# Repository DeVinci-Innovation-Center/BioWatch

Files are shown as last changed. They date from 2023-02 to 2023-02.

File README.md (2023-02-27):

# BioWatch
The BioWatch is a smartwatch prototyping for developing wearable biosensors and real-time data visualization. This electronic project aims at **facilitating the integration (or wireless connection) in a smartwatch of innovative wearable sensors**. The BioWatch allows rapid implementation of minimally invasive electrochemical biosensors. 

<p align="center">
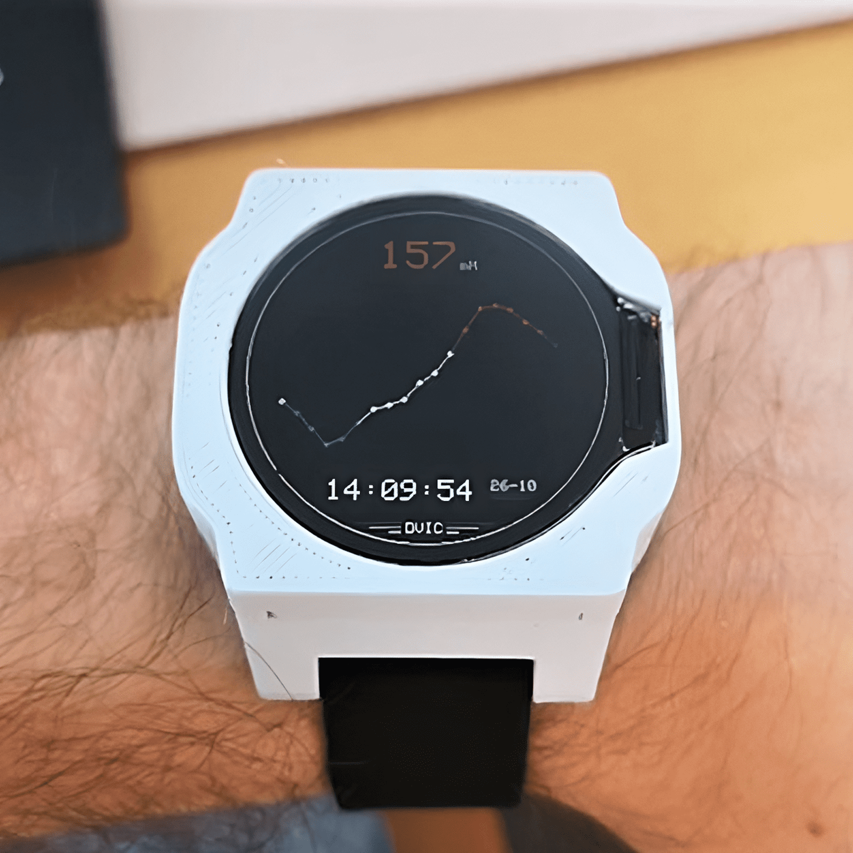
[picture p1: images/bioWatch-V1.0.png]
  
</p>

# System overview

<p align="center">
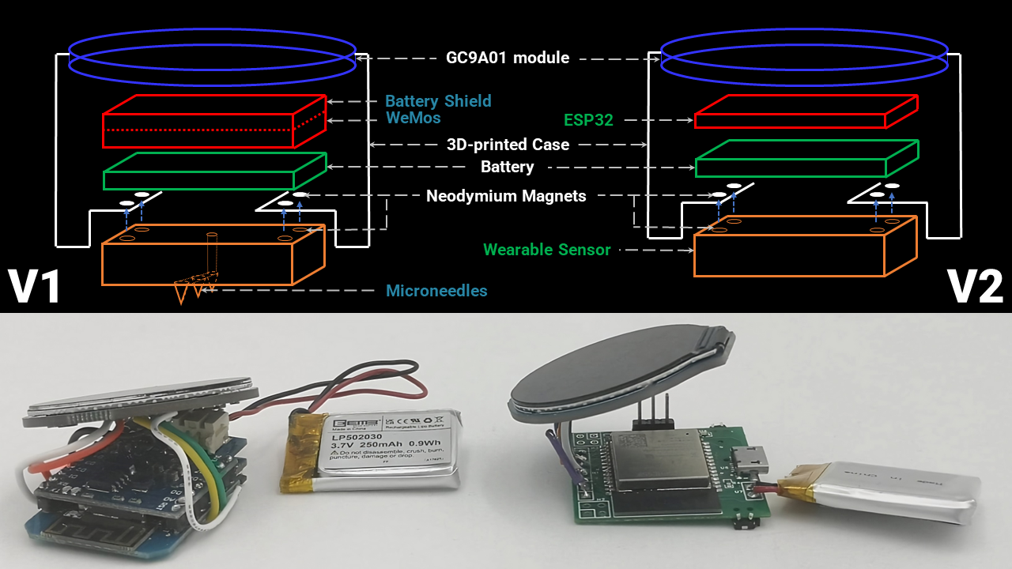
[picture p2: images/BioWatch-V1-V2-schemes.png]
  
</p>

# Requierments

To build the BioWatch you need the following components:
* A [CG9A01 round LCD screen](https://www.kubii.fr/ecrans-supports/3242-ecran-rond-lcd-1-28-pouces-3272496305625.html),
* An [ESP8266 WeMos D1 mini](https://www.amazon.fr/ESP8266-ESP-12F-D%C3%A9veloppement-NodeMCU-Compatible/dp/B093G72SHN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),
* A [battery shield](https://www.amazon.fr/AZDelivery-Batterie-lithium-Arduino-incluant/dp/B07XG817P8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) for WeMos D1 mini,
* A 3.7V 250mAh battery ref [LP502030](https://www.amazon.fr/EEMB-Batterie-Rechargeable-Navigation-Enregistreur/dp/B08FD3V6TF).
  
# Quickstart

**1. Download and 3D-print the [watch case](https://github.com/DeVinci-Innovation-Center/BioWatch/tree/main/hardware) of your choice.** 

*Version 1.0 includes the battery in the case, while V1.1 provides for the battery to be integrated in the bracelet.*

**2. Assembled the shield with the WeMos. Weld the GC9A01 using wires with the following dimensions:**
<p align="center">
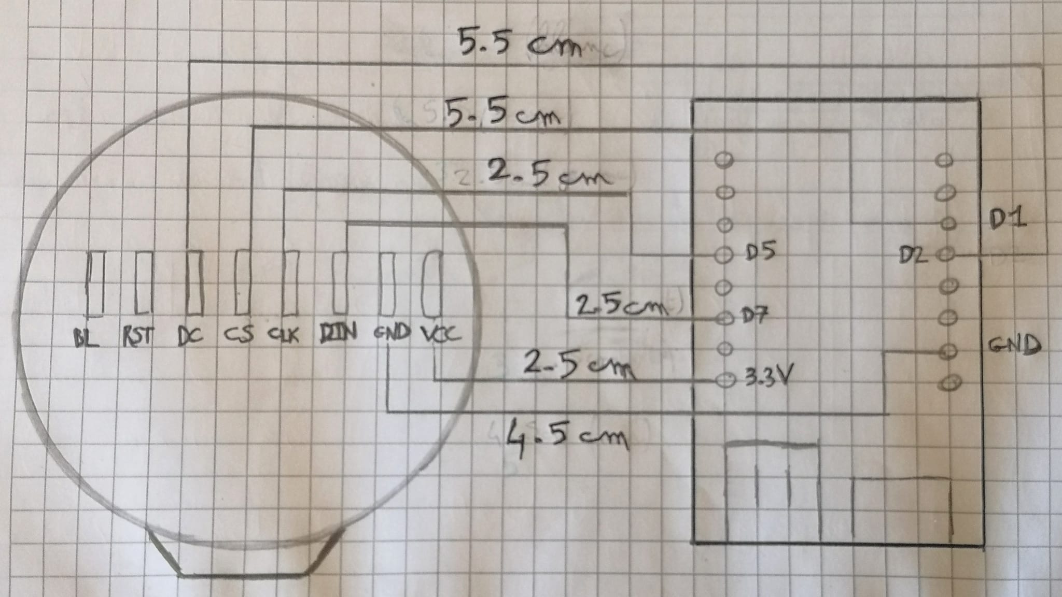
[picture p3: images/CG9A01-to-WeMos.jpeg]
  
</p>

**3. Upload a code in the [graphic_design folder](https://github.com/DeVinci-Innovation-Center/BioWatch/tree/main/ecflex-to-biowatch_wireless_communication/biowatch_client/graphic_design) to program the GC9A01 driver. [print_graph-and_time](https://github.com/DeVinci-Innovation-Center/BioWatch/tree/main/ecflex-to-biowatch_wireless_communication/biowatch_client/graphic_design/print_graph_and_time) is the functional interface to print sensor data.**

**4. Insert the charged battery into the JST port of the shield and carefully insert the assembly into the case.**

**5. Close the case with the lid and add a standard watchband.**

# Biosensor-to-smartwatch wireless communication
This project includes a wireless communication solution between an ec-Flex from [Zimmer&Peacock](https://www.zimmerpeacocktech.com/products/) and a homemade smartwatch. Find the Quickstart to connect and configure an ecFlex to the BioWatch on the from [Biosensor-to-smartwatch_wireless_communication GitHub page](https://github.com/DeVinci-Innovation-Center/Biosensor-to-smartwatch_wireless_communication), and [a tutorial](https://dvic.devinci.fr/tutorial/glucose-biosensor) to buid a wearable glucose sensor connected to the BioWatch.

# Project advancement & Future works

- [x] Write an Arduino script using the GFX library that displays time, glucose concentration, and temperature (numerical values) on the GC9A01 screen.
- [x] Write an Arduino script using the GFX library that displays a curve representing the glucose concentration evolution on the GC9A01 screen.
- [x] Assemble the BioWatch V1.0.
- [x] Minimize the size of the BioWatch by assembling the BioWatch V1.1 with the battery in the bracelet. 
- [x] Connect the ec-Flex to the BioWatch.
- [x] Design the BioWatch interface. Print time, date, sensor value and history.
- [ ] Design the BioWatch V2 PCB.
- [ ] Integrate a modular pulse sensor to the BioWatch V2 and read the data in real-time.

***

<p align="center">
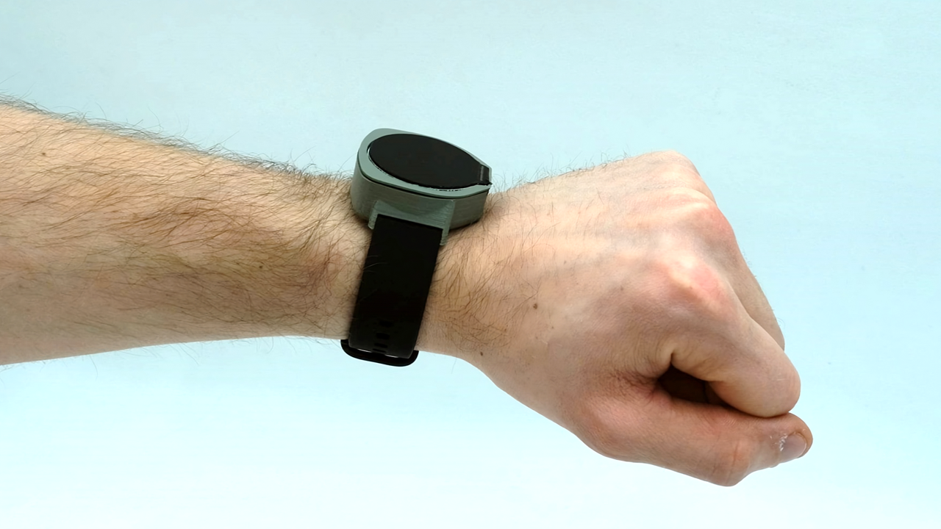
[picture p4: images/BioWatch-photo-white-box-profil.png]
  
</p>

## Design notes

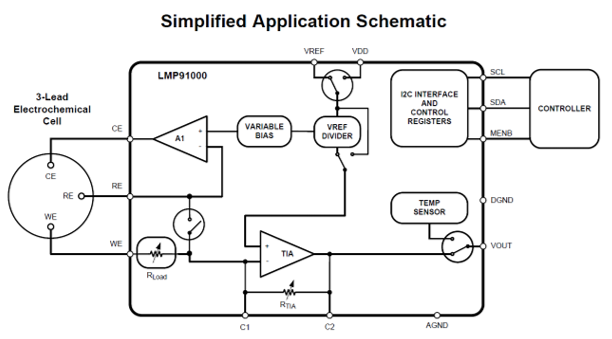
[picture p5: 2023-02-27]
images/LMP91000_AFE_simplified_schematic.png

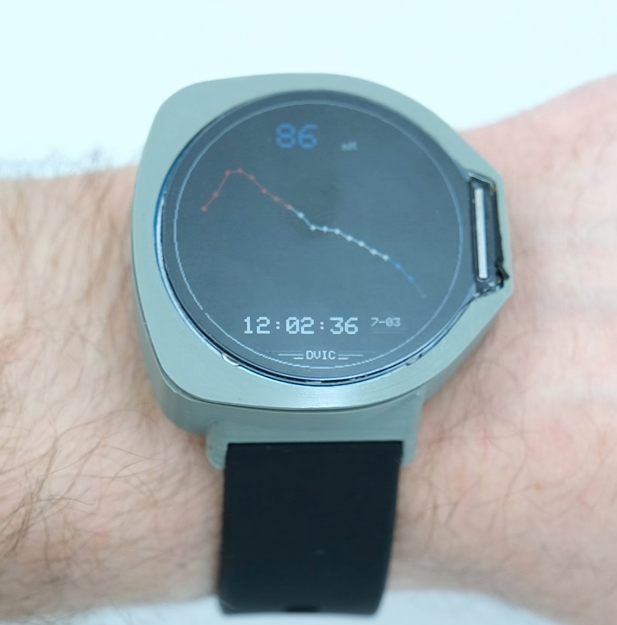
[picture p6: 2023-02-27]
hardware/case_modelizations_V1/bioWatch-V1.1.jpeg

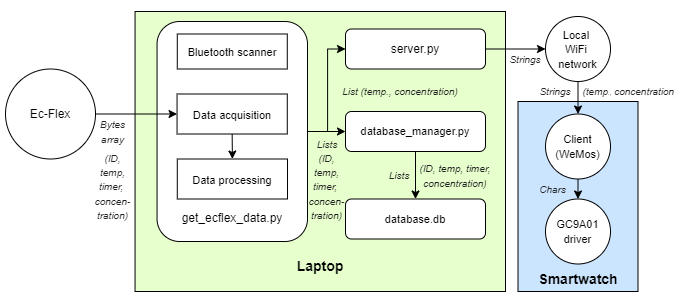
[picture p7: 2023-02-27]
images/deployment_diagramV2.png

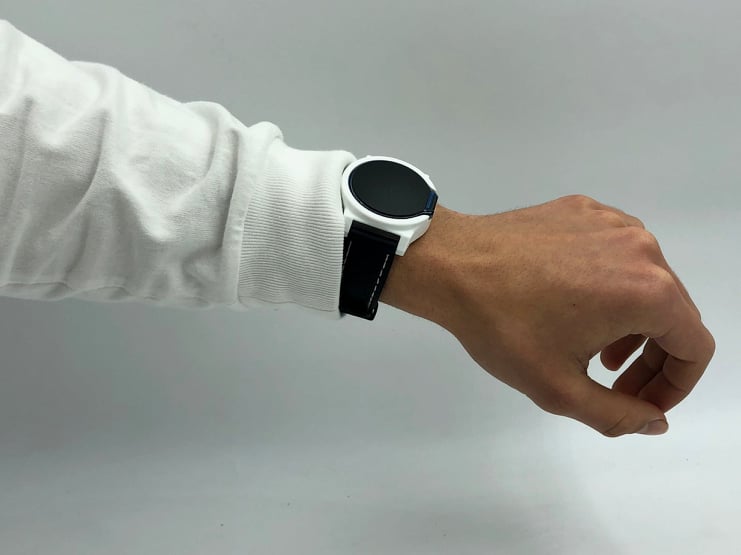
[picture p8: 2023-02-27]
images/SmartWatch_V0_white.jpg

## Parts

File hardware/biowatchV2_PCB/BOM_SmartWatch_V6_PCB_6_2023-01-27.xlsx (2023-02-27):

No. | Quantity | Comment | Designator | Footprint | Value | Manufacturer Part | Manufacturer | Supplier Part | Supplier
1 | 1 | CAPCER0.1UF16VX5R0603,CAPCER0.1UF25VX5R0603,CAPCER0.1UF16VX7R0603 | C1 | C0603 |  | CAPCER0.1UF16VX5R0603,CAPCER0.1UF25VX5R0603,CAPCER0.1UF16VX7R0603 | null | C9900012833 | LCSC
2 | 1 | 10uF | C2 | C0603 |  | 10uF | SAMSUNG(三星) | C15415 | LCSC
3 | 1 | PZ254V-11-07P | H1 | HDR-TH_7P-P2.54-V-M |  | PZ254V-11-07P | XFCN(兴飞) | C492406 | LCSC
4 | 2 | B-2100S04P-B110 | H2,H3 | HDR-TH_4P-P2.54-V-M-R2-C2-S2.54-1 |  | B-2100S04P-B110 | Ckmtw(灿科盟) | C124362 | LCSC
5 | 1 | H4: header 1x3 programmation serial | H4 | HEADER3L |  | Headers Pins2.54mm1*10P |  | C57369 | LCSC
6 | 1 | 1.2kΩ | R1 | R0603 |  | RMC06031.2K5%N | Tyohm(幸亚电阻) | C269681 | LCSC
7 | 2 | 1kΩ | R2,R3 | R0603 |  | 0603WAD1001T5E | UNI-ROYAL(厚声) | C51218 | LCSC
8 | 2 | 10kΩ | R4,R5 | R0603 |  | RNCS0603BKE10K0 | SEI(Stackpole Electronics Inc.) | C346660 | LCSC
9 | 1 | TA-3525-A3 | SW1 | SW-SMD_3P-L9.1-W3.5-P2.50-EH6.8 |  | TA-3525-A3 | Yuandi(元迪) | C514020 | LCSC
10 | 1 | ESP32-WROOM-32E-H4 | U0 | WIFI-SMD_ESP32-WROOM-32E |  | ESP32-WROOM-32E-H4 | ESPRESSIF(乐鑫) | C3013935 | LCSC
11 | 1 | TP4056 | U1 | ESOP-8_L4.9-W3.9-P1.27-LS6.0-BL-EP |  | TP4056 | TPOWER(天源) | C382139 | LCSC
12 | 1 | LED0603R | U2 | LED0603-R-RD |  | LED0603R | null | C9900017730 | LCSC
13 | 2 | LED0603B | U3,U4 | LED0603-RD |  | LED0603B | null | C9900005354 | LCSC
14 | 1 | BUTTON1 | U5 | SW-SMD_L7.8-W3.5-P4.00-EH |  | ButtonTACT_3x6x3.5 | null | C9900004514 | LCSC
15 | 1 | BUTTON2 | U6 | SW-SMD_L7.8-W3.5-P4.00-EH |  | ButtonTACT_3x6x3.5 | null | C9900004514 | LCSC
16 | 1 | DM254R-11-02-85 | U7 | HDR-TH_2P-P2.54-V-F |  | DM254R-11-02-85 | DEALON(德艺隆) | C2935973 | LCSC
17 | 1 | USB-MICRO-5P | U8 | MICRO-USB-SMD_MICRO-USB-A9 |  | USB-Micro-5P | null | C9900014288 | LCSC

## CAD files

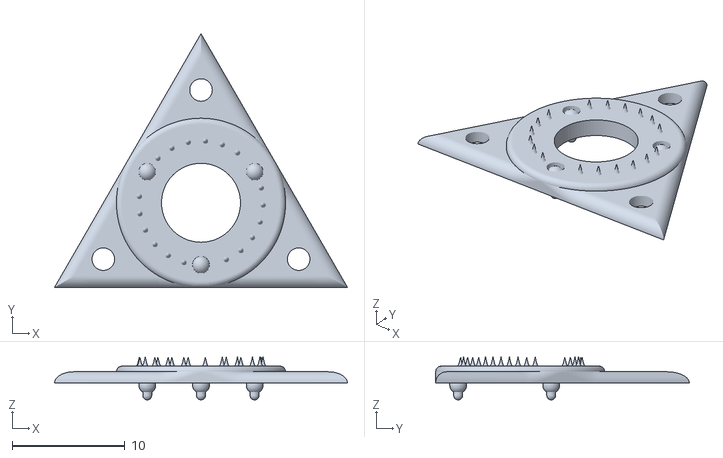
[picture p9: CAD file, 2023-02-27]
embedded_sensors/lmp91000/microneedles/Microneedles.stl
26.0 x 22.5 x 3.80

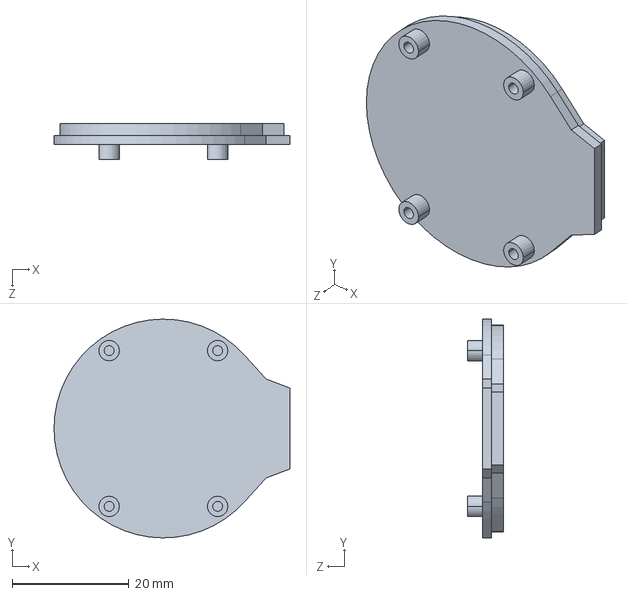
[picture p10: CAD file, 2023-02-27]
hardware/case_modelizations_V1/GC9A01.SLDPRT
40.5 x 37.5 x 6.10 mm

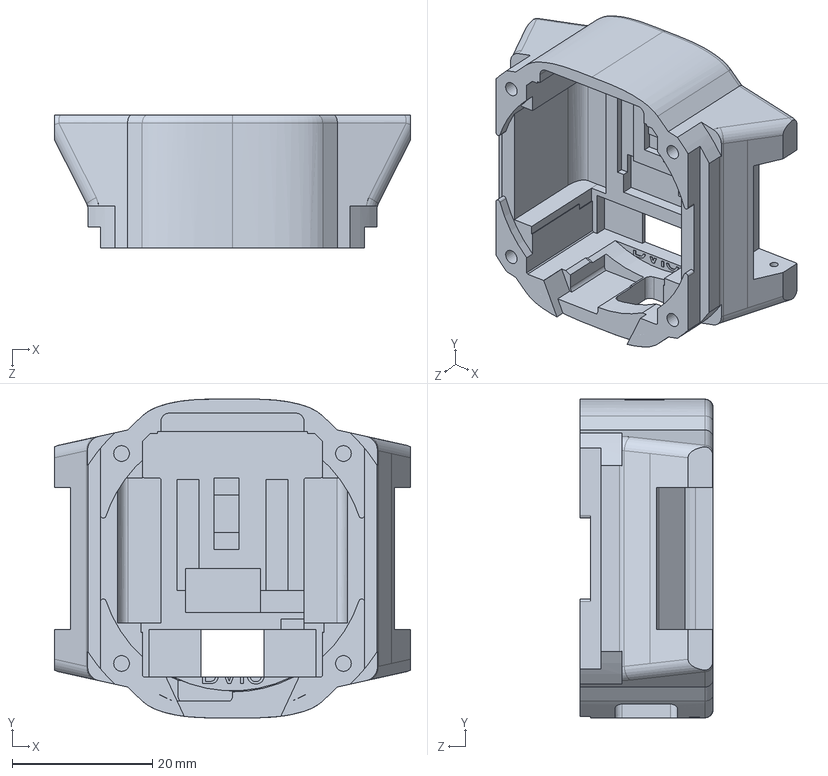
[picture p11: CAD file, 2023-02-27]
hardware/case_modelizations_V1/V1.0_wemos_battery_shield_battery/biowatch_case_V1.0.SLDPRT
50.7 x 45.4 x 19.0 mm

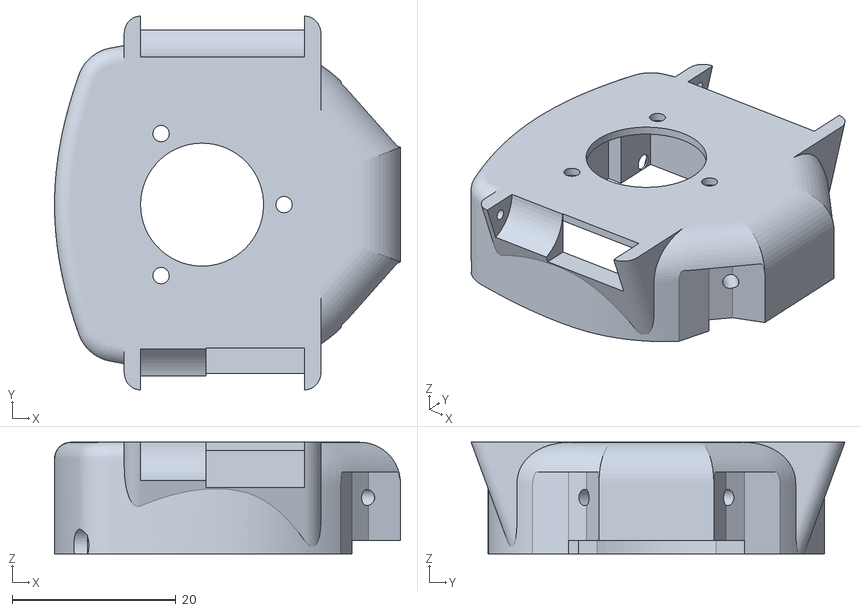
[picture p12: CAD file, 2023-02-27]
hardware/case_modelizations_V1/V1.1_wemos_battery_in_the_bracelet/biowatch_case_V1.1.stl
42.2 x 45.6 x 13.6

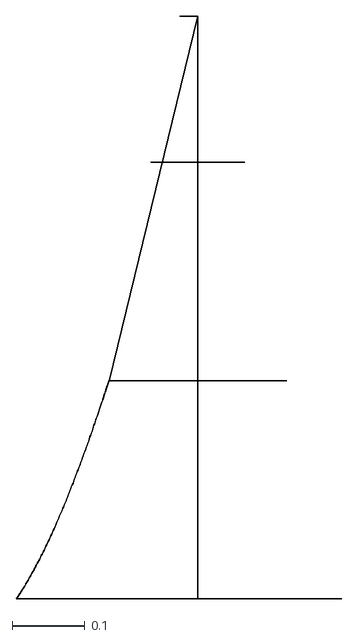
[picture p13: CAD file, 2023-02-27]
embedded_sensors/lmp91000/microneedles/AIGUILLE.dxf
0.448 x 0.802

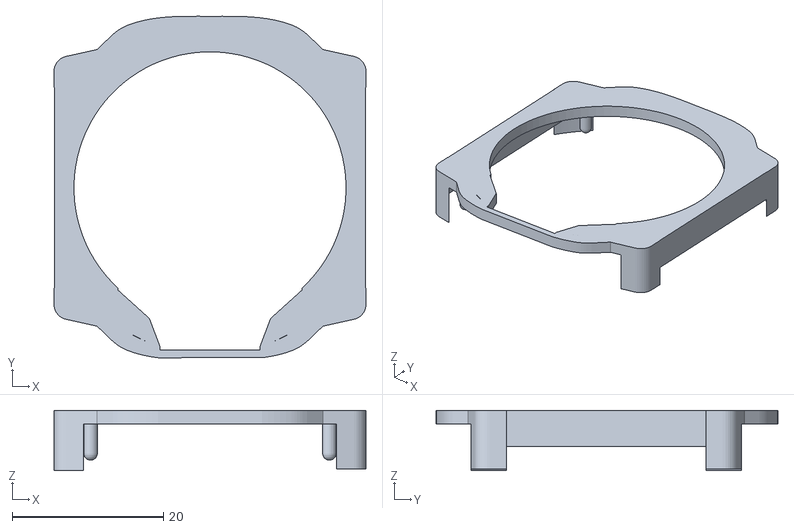
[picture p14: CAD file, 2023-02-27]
hardware/case_modelizations_V1/V1.0_wemos_battery_shield_battery/biowatch_hood-V1.0.stl
41.3 x 45.2 x 7.99

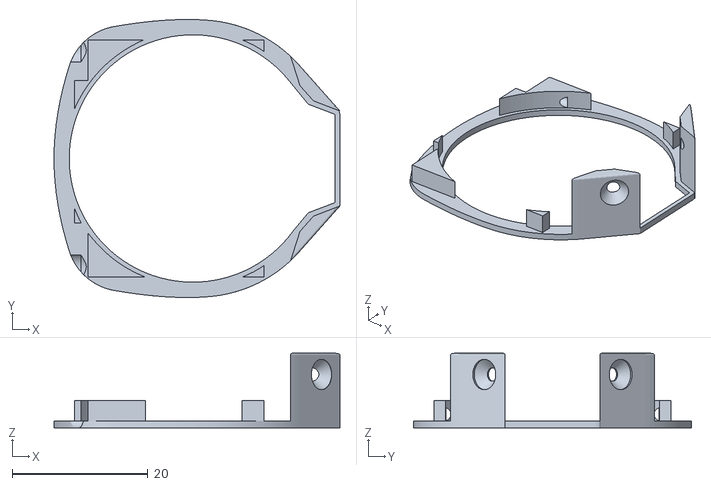
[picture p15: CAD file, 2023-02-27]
hardware/case_modelizations_V1/V1.1_wemos_battery_in_the_bracelet/biowatch_hood_V1.1.stl
42.2 x 41.0 x 11.0

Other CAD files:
hardware/case_modelizations_V1/V1.0_wemos_battery_shield_battery/biowatch_case_V1.0.stl

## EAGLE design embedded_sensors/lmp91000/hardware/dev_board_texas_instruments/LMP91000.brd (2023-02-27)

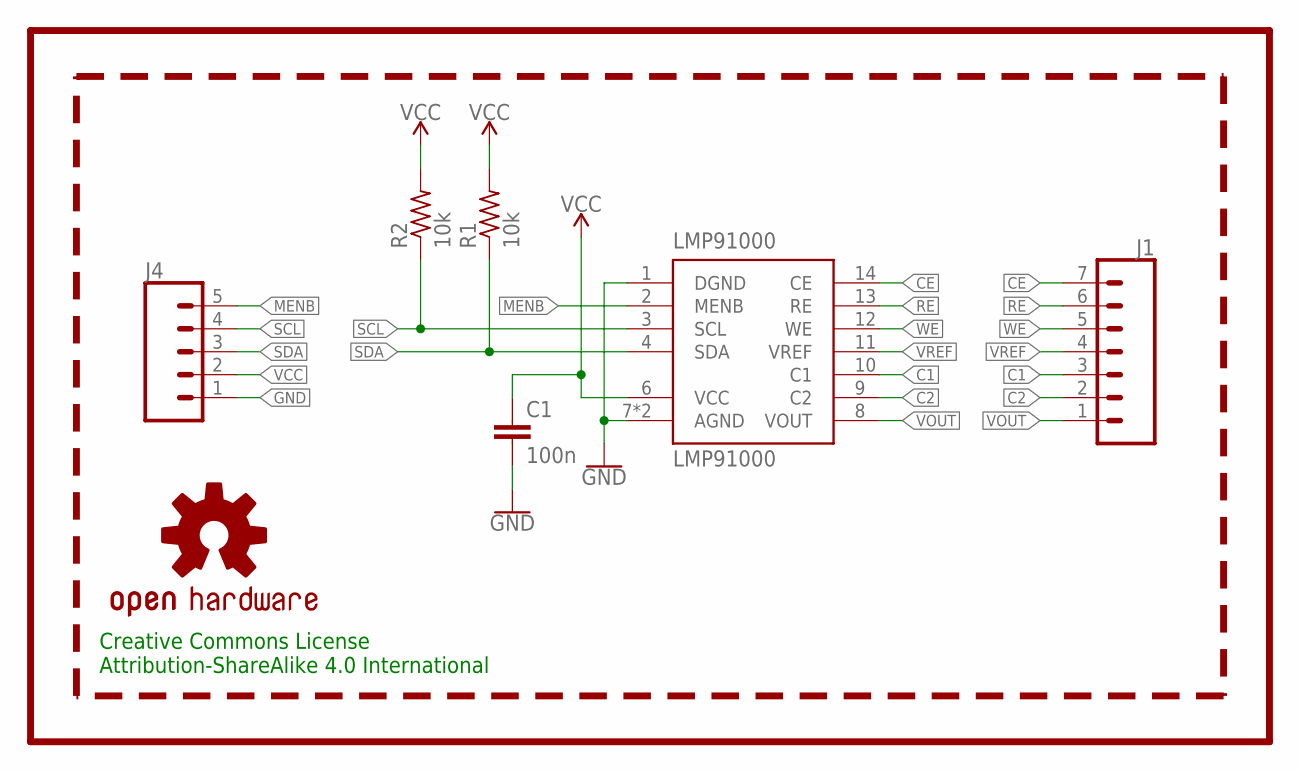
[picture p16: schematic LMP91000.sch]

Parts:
C1: 100n; C0402
J1: CONN_07NO_SILK; 1X07_NO_SILK
J4: CONN_05NO_SILK; 1X05_NO_SILK
LMP91000: LMP91000; WSON-14
LOGO1: OSHW-LOGOS; OSHW-LOGO-S
R1, R2: 10k; R0402
U$1: LINNES.LAB.05
U$2: LINNES.LAB.LOGO
U$3: REVISION.B; REV.B

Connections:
C1: J1.3, LMP91000.10 (C1)
C2: J1.2, LMP91000.9 (C2)
CE: J1.7, LMP91000.14 (CE)
GND: C1.2, J4.1, LMP91000.1 (DGND), LMP91000.7 (AGND), LMP91000.DAP (AGND)
MENB: J4.5, LMP91000.2 (MENB)
RE: J1.6, LMP91000.13 (RE)
SCL: J4.4, LMP91000.3 (SCL), R2.1
SDA: J4.3, LMP91000.4 (SDA), R1.1
VCC: C1.1, J4.2, LMP91000.6 (VCC), R1.2, R2.2
VOUT: J1.1, LMP91000.8 (VOUT)
VREF: J1.4, LMP91000.11 (VREF)
WE: J1.5, LMP91000.12 (WE)

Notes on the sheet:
Creative Commons License Attribution-ShareAlike 4.0 International

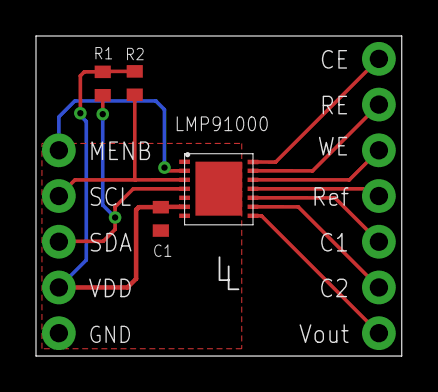
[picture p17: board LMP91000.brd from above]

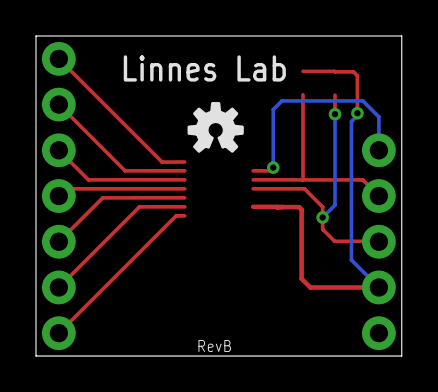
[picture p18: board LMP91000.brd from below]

Board: 2 copper layers, 20.3 x 17.8 mm, 10 parts (3 on the bottom side), 12 nets.

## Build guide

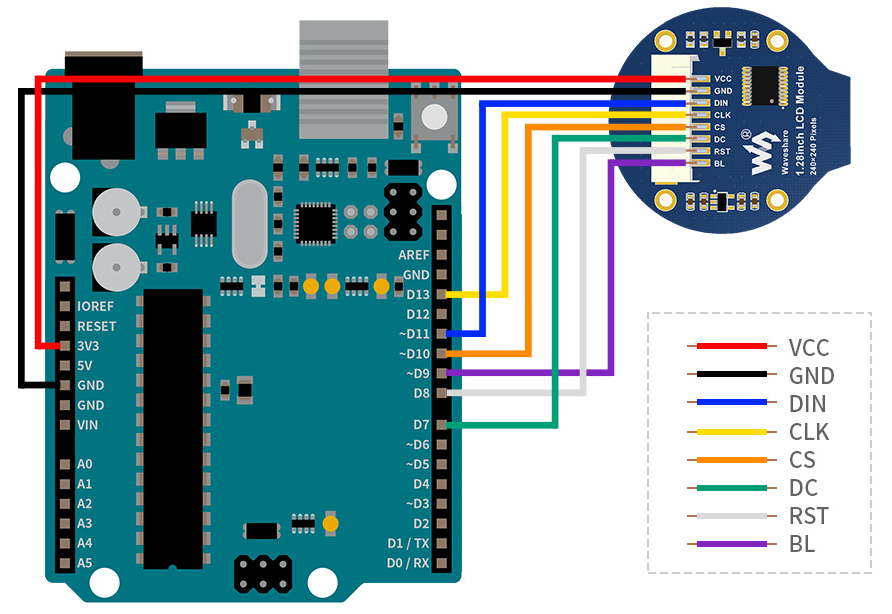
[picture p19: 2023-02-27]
images/GC9A01-wiring.PNG

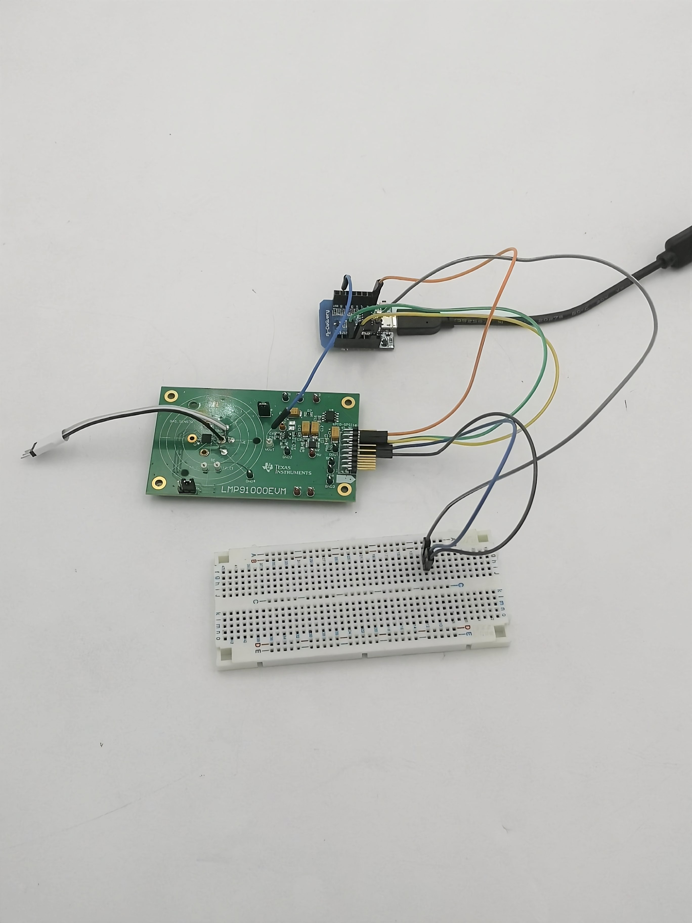
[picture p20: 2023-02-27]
images/Potentiostat-setup.jpeg

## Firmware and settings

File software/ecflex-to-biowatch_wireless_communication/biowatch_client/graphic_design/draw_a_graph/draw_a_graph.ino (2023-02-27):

#include <Wire.h> // I2C library
#include "Adafruit_GFX.h"
#include "Adafruit_SSD1306.h"
#include "Adafruit_GC9A01A.h"

#define TFT_DC 4 // SDA
#define TFT_CS 5 // SCL
#define SCREEN_WIDTH 128
#define SCREEN_HEIGHT 128

// Hardware SPI on Feather or other boards
Adafruit_GC9A01A tft(TFT_CS, TFT_DC);
Adafruit_SSD1306 display(SCREEN_WIDTH, SCREEN_HEIGHT, &Wire, -1);

#define LTBLUE 0xB6DF
#define LTTEAL 0xBF5F
#define LTGREEN 0xBFF7
#define LTCYAN 0xC7FF
#define LTRED 0xFD34
#define LTMAGENTA 0xFD5F
#define LTYELLOW 0xFFF8
#define LTORANGE 0xFE73
#define LTPINK 0xFDDF
#define LTPURPLE 0xCCFF
#define LTGREY 0xE71C

#define BLUE 0x001F
#define TEAL 0x0438
#define GREEN 0x07E0
#define CYAN 0x07FF
#define RED 0xF800
#define MAGENTA 0xF81F
#define YELLOW 0xFFE0
#define ORANGE 0xFC00
#define PINK 0xF81F
#define PURPLE 0x8010
#define GREY 0xC618
#define WHITE 0xFFFF
#define BLACK 0x0000

#define DKBLUE 0x000D
#define DKTEAL 0x020C
#define DKGREEN 0x03E0
#define DKCYAN 0x03EF
#define DKRED 0x6000
#define DKMAGENTA 0x8008
#define DKYELLOW 0x8400
#define DKORANGE 0x8200
#define DKPINK 0x9009
#define DKPURPLE 0x4010
#define DKGREY 0x4A49

int color = WHITE;

int xprev = 205;
int x0 = 205;
int x1 = 195;
int x2 = 185;
int x3 = 175;
int x4 = 165;
int x5 = 155;
int x6 = 145;
int x7 = 135;
int x8 = 125;
int x9 = 115;
int x10 = 105;
int x11 = 95;
int x12 = 85;
int x13 = 75;
int x14 = 65;
int x15 = 55;
int x16 = 45;
int x17 = 35;
int x18 = 25;

int yprev = 110; // yprev should be defined as the first sensor value received.
int y0y = 190;
int y1y = 110;
int y2y = 110;
int y3 = 110;
int y4 = 190;
int y5 = 190;
int y6 = 190;
int y7 = 190;
int y8 = 190;
int y9 = 190;
int y10 = 190;
int y11 = 190;
int y12 = 190;
int y13 = 190;
int y14 = 190;
int y15 = 190;
int y16 = 190;
int y17 = 190;
int y18 = 190;

int listx[19] = {x0, x1, x2, x3, x4, x5, x6, x7, x8, x9, x10, x11, x12, x13, x14, x15, x16, x17, x18};
int listy[19] = {y0y, y1y, y2y, y3, y4, y5, y6, y7, y8, y9, y10, y11, y12, y13, y14, y15, y16, y17, y18};

void setup()
{
  Serial.begin(115200);
  Serial.println("Start writting");
  tft.begin();
  tft.setRotation(1);
  tft.fillScreen(BLACK);
  delay(10);

// Draw a white circle
  tft.drawCircle(120, 120, 120, WHITE);
  delay(20);
  tft.drawCircle(120, 120, 119, WHITE);
  delay(25);
  tft.drawCircle(120, 120, 118, WHITE);
  delay(30);
  tft.drawCircle(120, 120, 117, WHITE);
  delay(30);
  tft.drawCircle(120, 120, 116, WHITE);
  delay(30);
  tft.drawCircle(120, 120, 115, WHITE);
  delay(60);
  tft.drawCircle(120, 120, 114, BLACK);
  delay(30);
  tft.drawCircle(120, 120, 115, BLACK);
  delay(30);
  tft.drawCircle(120, 120, 116, BLACK);
  delay(30);
  tft.drawCircle(120, 120, 117, BLACK);
  delay(25);
  tft.drawCircle(120, 120, 118, BLACK);
  delay(20);
  tft.drawCircle(120, 120, 120, BLACK);
  delay(200);

  //  tft.drawPixel(x18, y18, LTGREY);
  //  delay(80);
  //  tft.drawPixel(x17, y17, LTGREY);
  //  delay(80);
  //  tft.drawPixel(x16, y16, LTGREY);
  //  delay(80);
  //  tft.drawPixel(x15, y15, LTGREY);
  //  delay(80);
  //  tft.drawPixel(x14, y14, LTGREY);
  //  delay(80);
  //  tft.drawPixel(x13, y13, LTGREY);
  //  delay(80);
  //  tft.drawPixel(x12, y12, LTGREY);
  //  delay(80);
  //  tft.drawPixel(x11, y11, LTGREY);
  //  delay(80);
  //  tft.drawPixel(x10, y10, LTGREY);
  //  delay(80);
  //  tft.drawPixel(x9, y9, LTGREY);
  //  delay(80);
  //  tft.drawPixel(x8, y8, LTGREY);
  //  delay(80);
  //  tft.drawPixel(x7, y7, LTGREY);
  //  delay(80);
  //  tft.drawPixel(x6, y6, LTGREY);
  //  delay(80);
  //  tft.drawPixel(x5, y5, LTGREY);
  //  delay(80);
  //  tft.drawPixel(x4, y4, LTGREY);
  //  delay(80);
  //  tft.drawPixel(x3, y3, LTGREY);
  //  delay(80);
  //  tft.drawPixel(x2, y2y, LTGREY);
  //  delay(80);
  //  tft.drawPixel(x1, y1y, LTGREY);
  //  delay(80);
  //  tft.drawPixel(x0, y0y, LTGREY);
  //  delay(80);
  //  tft.drawPixel(xprev, yprev, LTGREY);
  //  delay(40);

  // Writte "DVIC" at the bottom of the screen
  tft.setCursor(108, 225);
  tft.setTextColor(WHITE);
  tft.setTextSize(1);
  tft.setTextWrap(false);
  tft.print("DVIC");
  delay(80);

  // Draw the 3 DVIC-left lines
  tft.drawFastHLine(75, 225, 30, DKGREY);
  tft.drawFastHLine(85, 228, 20, GREY);
  tft.drawPixel(84, 228, DKGREY);
  tft.drawFastHLine(98, 231, 7, WHITE);
  tft.drawPixel(97, 231, GREY);
  //  tft.drawPixel(96, 231, GREY);
  //  delay(60);

  // Draw the 3 DVIC-right lines
  tft.drawFastHLine(134, 225, 30, DKGREY);
  tft.drawFastHLine(134, 228, 20, GREY);
  tft.drawPixel(155, 225, DKGREY);
  tft.drawFastHLine(134, 231, 7, WHITE);
  tft.drawPixel(141, 231, GREY);
  delay(80);

  // Writte concentration unit
  tft.setCursor(136, 38);
  tft.setTextColor(LTGREY);
  tft.setTextSize(1);
  tft.setTextWrap(false);
  tft.print(" mM");

  //  tft.drawRect(25, 49, 190, 143, DKTEAL);     // Centered inner rectangle
  //  tft.drawRect(48, 24, 144, 192, DKGREY);     // Centered outer rectangle
  //  tft.drawRect(24, 48, 192, 144, DKGREY);     // Centered outer rectangle
  //  tft.drawRect(35, 35, 170, 170, DKMAGENTA);  // Large centered square, 0 pixel margin
  //  tft.drawRect(40, 40, 160, 160, DKGREY);     // Square centered with 10px margin
  //  tft.drawLine(48, 24, 192, 216, LTBLUE);    // Diagonal 1 of outer rectangle
  //  tft.drawLine(192, 24, 48, 216, LTBLUE);    // Diagonal 2 of outer rectangle
  //  tft.drawLine(0, 0, 240, 240, DKMAGENTA);     // Diagonal 1 of the large square
  //  tft.drawLine(0, 240, 240, 0, DKMAGENTA);     // Diagonal 2 of the large square
}

void loop()
{
  int listcg[] = {110, 105, 97, 86, 75, 79, 90, 100, 103, 107, 119, 126, 140, 158, 174, 176, 173, 164, 157, 150, 142, 131, 130, 128, 122, 117, 112, 110, 105, 97, 86, 77, 79, 90, 100, 103, 107, 119, 130, 147, 160, 180, 182, 176, 164, 157, 150, 142, 131, 130, 128, 122, 117, 112};
  for (int i = 0; i <= 52; i++)
  {                             // Update cg loop
    int cgreceived = listcg[i]; // Simulate a new value received
    Serial.print("cgreceived: ");
    Serial.println(cgreceived);

    // Shift the list from left to right to make room for the new y0 value
    shiftright(listy); 

    // Add y0 to the liste //
    listy[1] = converttopixel(cgreceived);

    Serial.print("The new y0 is: ");
    Serial.println(listy[0]);
    Serial.print("The new y1 is: ");
    Serial.println(listy[1]);
    Serial.print("The new y2 is: ");
    Serial.println(listy[2]);
    Serial.print("The new y3 is: ");
    Serial.println(listy[3]);

    color = WHITE;
    tft.fillRect(87, 23, 52, 21, BLACK); // Refresh the glucose concentration value printed

    tft.setCursor(87, 23);
    if (cgreceived >= 150) // High glycemia. Risk of hyperglycemic crisis
    { // 150 mMol
      color = RED;
    }
    if (cgreceived <= 100) // Low glycemia. Risk of hypoglycemic crisis
    { // 100 mMol
      color = TEAL;
    }
    tft.setTextColor(color); // color is WHITE by default
    tft.setTextSize(3);
    tft.setTextWrap(false);
    tft.print(String(cgreceived));

    for (int j = 1; j <= 19; j++)
    { // Draw pixel from x0 = 190 to x19 = 25
      color = WHITE;
      if (listy[j] <= 100)
      { // The 100th pixel correspond to 140mMol
        color = RED;
      }
      if (listy[j] >= 150)
      { // The 150th pixel correspond to 90mMol
        color = TEAL;
      }
      tft.drawPixel(listx[j], listy[j], color); // Draw pixel [xj,yj]

      tft.drawPixel(listx[j] + 1, listy[j], color); // Draw a diamond around pixel [xj,yj]
      tft.drawPixel(listx[j], listy[j] + 1, color);
      tft.drawPixel(listx[j] - 1, listy[j], color);
      tft.drawPixel(listx[j], listy[j] - 1, color);

      tft.drawPixel(listx[j] + 2, listy[j], color);
      tft.drawPixel(listx[j], listy[j] + 2, color);
      tft.drawPixel(listx[j] - 2, listy[j], color);
      tft.drawPixel(listx[j], listy[j] - 2, color);

      tft.drawPixel(listx[j] + 1, listy[j] + 1, color);
      tft.drawPixel(listx[j] - 1, listy[j] + 1, color);
      tft.drawPixel(listx[j] + 1, listy[j] - 1, color);
      tft.drawPixel(listx[j] - 1, listy[j] - 1, color);

      Serial.print("A l'itération ");
      Serial.print(i);
      Serial.print(", l'y du pixel ");
      Serial.print(j);
      Serial.print(" vaut: ");
      Serial.println(listy[j]);
    }
    // Calcul of yprev
    yprev = listy[1] + round((5 * (listy[1] - listy[2]) + 2 * (listy[2] - listy[3]) + listy[1] - listy[2]) / 8 + (listy[1] - listy[2]) / 2);

    if (yprev > 188)
    { // High limit to avoid going off screen
      yprev = 188;
    }
    if (yprev < 52)
    { // Low limit to avoid going off screen
      yprev = 52;
    }

    Serial.print("The new value of yprev is: ");
    Serial.println(yprev);

    tft.drawPixel(xprev, yprev, GREY); // Draw pixel [xprev, yprev]

    tft.drawPixel(xprev + 1, yprev, DKGREY);
    tft.drawPixel(xprev, yprev + 1, DKGREY);
    tft.drawPixel(xprev - 1, yprev, DKGREY);
    tft.drawPixel(xprev, yprev - 1, DKGREY);

    tft.drawPixel(xprev + 2, yprev, DKGREY);
    tft.drawPixel(xprev, yprev + 2, DKGREY);
    tft.drawPixel(xprev - 2, yprev, DKGREY);
    tft.drawPixel(xprev, yprev - 2, DKGREY);

    tft.drawPixel(xprev + 1, yprev + 1, DKGREY);
    tft.drawPixel(xprev - 1, yprev + 1, DKGREY);
    tft.drawPixel(xprev + 1, yprev - 1, DKGREY);
    tft.drawPixel(xprev - 1, yprev - 1, DKGREY);

    for (int k = 1; k <= 17; k++)
    { // Draw lines between all points
      color = WHITE;
      if (listy[k] <= 100)
      { // The 100th pixel correspond to 140mMol
        color = RED;
      }
      if (listy[k] >= 150)
      { // The 150th pixel correspond to 90mMol
        color = TEAL;
      }
      tft.drawLine(listx[k], listy[k], listx[k + 1], listy[k + 1], color);
      //      delay(25);
      tft.drawLine(listx[1], listy[1], xprev, yprev, DKGREY);
      tft.drawLine(listx[1], listy[1] - 1, xprev, yprev, DKGREY);
      tft.drawLine(listx[1], listy[1] + 1, xprev, yprev, DKGREY);
    }

    delay(2000); // Update frequency

    // Refresh graph after 2 seconds
    tft.fillRect(26, 50, 188, 141, BLACK); 
    tft.fillRect(23, 54, 5, 135, BLACK);
    tft.fillRect(25, 190, 190, 3, BLACK);
  }
}

// Shift right function
void shiftright(int list[])
{
  for (int i = 19; i >= 1; i--)
  {
    list[i] = list[i - 1];
  }
}

// Convert the value receive in graphical coordinates
int converttopixel(int cg)
{
  int y = 240 - (cg - 7);
  return y;
}

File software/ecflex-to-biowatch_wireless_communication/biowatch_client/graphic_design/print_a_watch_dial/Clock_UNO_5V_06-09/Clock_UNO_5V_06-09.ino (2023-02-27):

/*
   Arduino Watch Lite Version
   You may find full version at: https://github.com/moononournation/ArduinoWatch
*/

/*******************************************************************************
 * Start of Arduino_GFX setting
 * 
 * Arduino_GFX try to find the settings depends on selected board in Arduino IDE
 * Or you can define the display dev kit not in the board list
 * Defalult pin list for non display dev kit:
 * Arduino Nano, Micro and more: CS:  9, DC:  8, RST:  7, BL:  6, SCK: 13, MOSI: 11, MISO: 12
 * ESP32 various dev board     : CS:  5, DC: 27, RST: 33, BL: 22, SCK: 18, MOSI: 23, MISO: nil
 * ESP32-C3 various dev board  : CS:  7, DC:  2, RST:  1, BL:  3, SCK:  4, MOSI:  6, MISO: nil
 * ESP32-S2 various dev board  : CS: 34, DC: 35, RST: 33, BL: 21, SCK: 36, MOSI: 35, MISO: nil
 * ESP32-S3 various dev board  : CS: 40, DC: 41, RST: 42, BL: 48, SCK: 36, MOSI: 35, MISO: nil
 * ESP8266 various dev board   : CS: 15, DC:  4, RST:  2, BL:  5, SCK: 14, MOSI: 13, MISO: 12
 * Raspberry Pi Pico dev board : CS: 17, DC: 27, RST: 26, BL: 28, SCK: 18, MOSI: 19, MISO: 16
 * RTL8720 BW16 old patch core : CS: 18, DC: 17, RST:  2, BL: 23, SCK: 19, MOSI: 21, MISO: 20
 * RTL8720_BW16 Official core  : CS:  9, DC:  8, RST:  6, BL:  3, SCK: 10, MOSI: 12, MISO: 11
 * RTL8722 dev board           : CS: 18, DC: 17, RST: 22, BL: 23, SCK: 13, MOSI: 11, MISO: 12
 * RTL8722_mini dev board      : CS: 12, DC: 14, RST: 15, BL: 13, SCK: 11, MOSI:  9, MISO: 10
 * Seeeduino XIAO dev board    : CS:  3, DC:  2, RST:  1, BL:  0, SCK:  8, MOSI: 10, MISO:  9
 * Teensy 4.1 dev board        : CS: 39, DC: 41, RST: 40, BL: 22, SCK: 13, MOSI: 11, MISO: 12
 ******************************************************************************/
#include <Arduino_GFX_Library.h>

#define GFX_BL DF_GFX_BL // default backlight pin, you may replace DF_GFX_BL to actual backlight pin

/* More dev device declaration: https://github.com/moononournation/Arduino_GFX/wiki/Dev-Device-Declaration */
#if defined(DISPLAY_DEV_KIT)
Arduino_GFX *gfx = create_default_Arduino_GFX();
#else /* !defined(DISPLAY_DEV_KIT) */

/* More data bus class: https://github.com/moononournation/Arduino_GFX/wiki/Data-Bus-Class */
Arduino_DataBus *bus = new Arduino_SWSPI(7 /* DC */, 10 /* CS */, 13 /* SCK */, 11 /* MOSI */, -1 /* MISO */);

/* More display class: https://github.com/moononournation/Arduino_GFX/wiki/Display-Class */
Arduino_GFX *gfx = new Arduino_GC9A01(bus, 7 /* RST */, 0 /* rotation */, true /* IPS */);

#endif /* !defined(DISPLAY_DEV_KIT) */
/*******************************************************************************
 * End of Arduino_GFX setting
 ******************************************************************************/

#define BACKGROUND BLACK
#define MARK_COLOR WHITE
#define SUBMARK_COLOR DARKGREY // LIGHTGREY
#define HOUR_COLOR WHITE
#define MINUTE_COLOR BLUE // LIGHTGREY
#define SECOND_COLOR RED

#define SIXTIETH 0.016666667
#define TWELFTH 0.08333333
#define SIXTIETH_RADIAN 0.10471976
#define TWELFTH_RADIAN 0.52359878
#define RIGHT_ANGLE_RADIAN 1.5707963

static uint8_t conv2d(const char *p)
{
    uint8_t v = 0;
    return (10 * (*p - '0')) + (*++p - '0');
}

static int16_t w, h, center;
static int16_t hHandLen, mHandLen, sHandLen, markLen;
static float sdeg, mdeg, hdeg;
static int16_t osx = 0, osy = 0, omx = 0, omy = 0, ohx = 0, ohy = 0; // Saved H, M, S x & y coords
static int16_t nsx, nsy, nmx, nmy, nhx, nhy;                         // H, M, S x & y coords
static int16_t xMin, yMin, xMax, yMax;                               // redraw range
static int16_t hh, mm, ss;
static unsigned long targetTime; // next action time

static int16_t *cached_points;
static uint16_t cached_points_idx = 0;
static int16_t *last_cached_point;

void setup(void)
{
    gfx->begin();
    gfx->fillScreen(BACKGROUND);

#ifdef GFX_BL
    pinMode(GFX_BL, OUTPUT);
    digitalWrite(GFX_BL, HIGH);
#endif

    // init LCD constant
    w = gfx->width();
    h = gfx->height();
    if (w < h)
    {
        center = w / 2;
    }
    else
    {
        center = h / 2;
    }
    hHandLen = center * 3 / 8;
    mHandLen = center * 2 / 3;
    sHandLen = center * 5 / 6;
    markLen = sHandLen / 6;
    cached_points = (int16_t *)malloc((hHandLen + 1 + mHandLen + 1 + sHandLen + 1) * 2 * 2);

    // Draw 60 clock marks
    draw_round_clock_mark(
    // draw_square_clock_mark(
        center - markLen, center,
        center - (markLen * 2 / 3), center,
        center - (markLen / 2), center);

    hh = conv2d(__TIME__);
    mm = conv2d(__TIME__ + 3);
    ss = conv2d(__TIME__ + 6);

    targetTime = ((millis() / 1000) + 1) * 1000;
}

void loop()
{
    unsigned long cur_millis = millis();
    if (cur_millis >= targetTime)
    {
        targetTime += 1000;
        ss++; // Advance second
        if (ss == 60)
        {
            ss = 0;
            mm++; // Advance minute
            if (mm > 59)
            {
                mm = 0;
                hh++; // Advance hour
                if (hh > 23)
                {
                    hh = 0;
                }
            }
        }
    }

    // Pre-compute hand degrees, x & y coords for a fast screen update
    sdeg = SIXTIETH_RADIAN * ((0.001 * (cur_millis % 1000)) + ss); // 0-59 (includes millis)
    nsx = cos(sdeg - RIGHT_ANGLE_RADIAN) * sHandLen + center;
    nsy = sin(sdeg - RIGHT_ANGLE_RADIAN) * sHandLen + center;
    if ((nsx != osx) || (nsy != osy))
    {
        mdeg = (SIXTIETH * sdeg) + (SIXTIETH_RADIAN * mm); // 0-59 (includes seconds)
        hdeg = (TWELFTH * mdeg) + (TWELFTH_RADIAN * hh);   // 0-11 (includes minutes)
        mdeg -= RIGHT_ANGLE_RADIAN;
        hdeg -= RIGHT_ANGLE_RADIAN;
        nmx = cos(mdeg) * mHandLen + center;
        nmy = sin(mdeg) * mHandLen + center;
        nhx = cos(hdeg) * hHandLen + center;
        nhy = sin(hdeg) * hHandLen + center;

        // redraw hands
        redraw_hands_cached_draw_and_erase();

        ohx = nhx;
        ohy = nhy;
        omx = nmx;
        omy = nmy;
        osx = nsx;
        osy = nsy;

        delay(1);
    }
}

void draw_round_clock_mark(int16_t innerR1, int16_t outerR1, int16_t innerR2, int16_t outerR2, int16_t innerR3, int16_t outerR3)
{
  float x, y;
  int16_t x0, x1, y0, y1, innerR, outerR;
  uint16_t c;

  for (uint8_t i = 0; i < 60; i++)
  {
    if ((i % 15) == 0)
    {
      innerR = innerR1;
      outerR = outerR1;
      c = MARK_COLOR;
    }
    else if ((i % 5) == 0)
    {
      innerR = innerR2;
      outerR = outerR2;
      c = MARK_COLOR;
    }
    else
    {
      innerR = innerR3;
      outerR = outerR3;
      c = SUBMARK_COLOR;
    }

    mdeg = (SIXTIETH_RADIAN * i) - RIGHT_ANGLE_RADIAN;
    x = cos(mdeg);
    y = sin(mdeg);
    x0 = x * outerR + center;
    y0 = y * outerR + center;
    x1 = x * innerR + center;
    y1 = y * innerR + center;

    gfx->drawLine(x0, y0, x1, y1, c);
  }
}
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
